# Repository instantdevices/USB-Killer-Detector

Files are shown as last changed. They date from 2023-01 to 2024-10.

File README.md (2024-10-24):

<p align="center">
    <strong>USB KILLER DETECTOR</strong>
</p>
<p>
UBS Kill is a pen-testing device that looks like a regular USB flash drive. When these USB flash drives are connected into a USB port of your personal computer, then the 5V found in the USB port is converted into about 220 Volts. Needless to say that the computer can be physically damaged in seconds, resulting in the spending of money and resources to replace broken parts.
</p>
<p>
<strong>Key Features:</strong>
</p>
<ul>
<li>
Detects these flash drives in seconds.
</li>
<li>
Fits in your hand and pocket.
</li>
<li>
Relatively low manufacturing costs.
</li>
<li>
Universally compatible with almost every micro-USB charger.
</li>
<li>
Use it prior to connect an unknown flash drive to your valuable hardware.
</li>
<li>
Confidently proceed as usual upon a negative result.
</li>
</ul>
<p>
<strong>Available Versions:</strong>
</p>
<ul>
<li>
Version #1: (Battery-Powered) This version uses a battery to source for energy. People can carry this device with them as it is portable.
</li>
<li>
Version #2: (No Battery-Powered) It is a commercial challenge to ship devices with an ion-based battery due to current global regulations. This version does NOT use any battery at all, instead, energy is sourced from a standard micro-USB charging cable.
</li>
</ul>

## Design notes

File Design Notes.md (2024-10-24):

<p align="center">
    <strong>DESIGN NOTES</strong>
</p>
<p><strong>Find notes below:</strong></p>
<ul>

<li>PCB is two-layer SMD.</strong></li>

<li>Design rules are Seeeds 2-layer standard rules.</li>

<li>Circuit has three sections, Micro USB charger, 5V boost converter and killer detector (including safety clamper).</li>

<li>
3-LEDs:
<ul>
<li>Power LED</li>
<li>Battery charger status LED</li>
<li>Killer detection LED</li>
</ul>
</li>

<li>Battery is 3.7V single cell Lithium Iron (1000mAh capacity). Charging current is 100mA (check schematic).</li>

<li>PCB size is mentioned in the given images. Basically ~3.6cmx6.2cm.</li>

<li>Mounting holes are 3mm.</li>

<li>The battery can be placed under the PCB. There is small rounded place to feed the battery wires from bottom side to top.</li>

<li>Some test points were added in case users need to check/debug circuit sections.</li>

<li>SJ1 jumper was added to reset the push button IC.</li>

<li>Additional external LED was added to the same Killer LED output. If users need to get out killer LED from the board to enclosure, skip board LED and R7 resistor and add R13 resistor. Then users can use EXT_LED header (2.54mm pitch) to drive external LED (LED will be standard 3mm, Vf=2.2V, If=20mA, these are approximates).</li>

<li>Added 4 fiducials for fab support.</li>

<li>S1 is the turn on/off button.</li>

<li>When a killer USB is detected, circuit will show the red LED output until removed. On low battery, red LED will turn on for the blink of an eye.</li>
</ul>

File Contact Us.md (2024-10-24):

<p align="center">
<strong>CONTACT INFORMATION</strong>
</p>
<p><em>
Instant Devices<br>
Attn: USB Killer Detector<br>
11425 SW 44th St<br>
Miami, FL 33165<br>
United States<br>
Email: instant.devices@yahoo.com
</em></p>

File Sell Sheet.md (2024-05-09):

<p align="center">
    <strong>USB KILLER DETECTOR</strong>
</p>
<p align="center">
    <strong></strong>
</p>
<p align="center">
    <strong>SELL SHEET</strong>
</p>
<p>
    UBS Kill is a pen-testing device that looks like a regular USB flash drive.
    When these USB flash drives are connected into a USB port of your personal computer, then the 5V found in the USB port is converted into
    about 220 Volts. Needless to say that the computer
    can be physically damaged in seconds, resulting in the spending of money and resources
    to replace broken parts.
</p>
<p>
    Key Features:
</p>
<p>
    - Detects these flash drives in seconds.
</p>
<p>
    - Fits in your hand and pocket.
</p>
<p>
    - Relatively low manufacturing costs.
</p>
<p>
    - Universally compatible with almost any micro-USB charger.
</p>
<p>
    - Use it prior to connect an unknown flash drive to your valuable hardware.
</p>
<p>
    - Confidently proceed as usual upon a negative result.
</p>

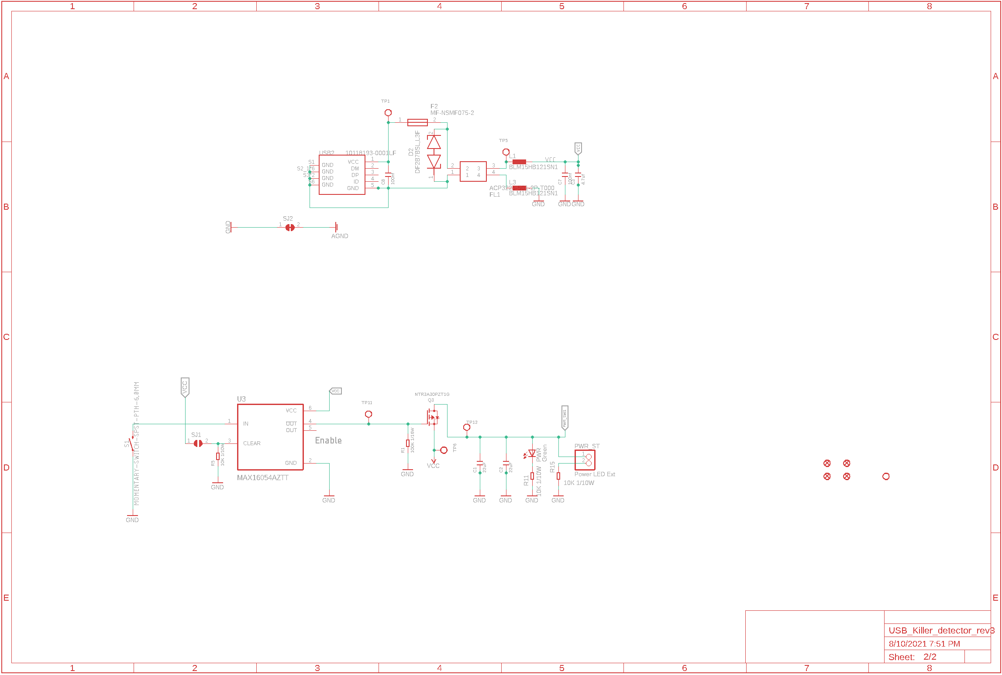
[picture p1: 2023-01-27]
Project/V2/Schematics/Schematics 2 of 2.png

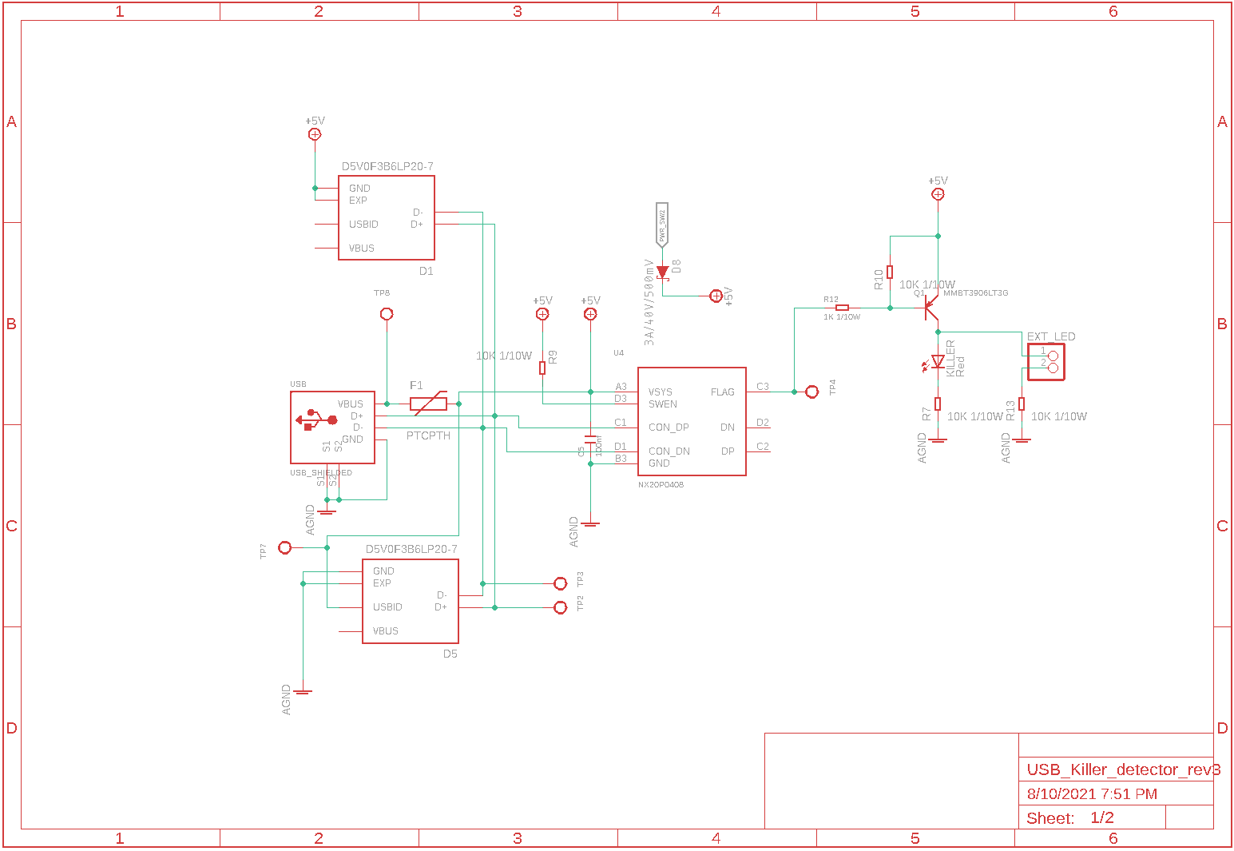
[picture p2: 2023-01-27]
Project/V2/Schematics/Schematics 1 of 2.png

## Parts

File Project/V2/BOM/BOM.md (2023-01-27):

<p align="center">
    <strong>USB KILLER DETECTOR V2</strong>
</p>
<p align="center">
    <strong></strong>
</p>
<p align="center">
    <strong>BOM</strong>
</p>
<table border="0" cellspacing="0" cellpadding="0" width="1333">
    <tbody>
        <tr>
            <td width="75" nowrap="" valign="bottom">
                <p>
                    <strong>Designator</strong>
                </p>
            </td>
            <td width="177" nowrap="" valign="bottom">
                <p>
                    <strong>Manufacturer Part Number</strong>
                </p>
            </td>
            <td width="1049" nowrap="" valign="bottom">
                <p>
                    <strong>DigiKey Link</strong>
                </p>
            </td>
            <td width="32" nowrap="" valign="bottom">
                <p>
                    <strong>Qty</strong>
                </p>
            </td>
        </tr>
        <tr>
            <td width="75" nowrap="" valign="bottom">
                <p>
                    C1
                </p>
            </td>
            <td width="177" nowrap="" valign="bottom">
                <p>
                    GRM319R61C226ME15D
                </p>
            </td>
            <td width="1049" nowrap="" valign="bottom">
                <p>
                    https://www.digikey.com/en/products/detail/murata-electronics/GRM319R61C226ME15D/4905568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
                </p>
            </td>
            <td width="32" nowrap="" valign="bottom">
                <p align="center">
                    1
                </p>
            </td>
        </tr>
        <tr>
            <td width="75" nowrap="" valign="bottom">
                <p>
                    C2
                </p>
            </td>
            <td width="177" nowrap="" valign="bottom">
                <p>
                    GRM319R61C226ME15D
                </p>
            </td>
            <td width="1049" nowrap="" valign="bottom">
                <p>
                    https://www.digikey.com/en/products/detail/murata-electronics/GRM319R61C226ME15D/4905568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
                </p>
            </td>
            <td width="32" nowrap="" valign="bottom">
                <p align="center">
                    1
                </p>
            </td>
        </tr>
        <tr>
            <td width="75" nowrap="" valign="bottom">
                <p>
                    C3
                </p>
            </td>
            <td width="177" nowrap="" valign="bottom">
                <p>
                    CC0805KKX5R8BB475
                </p>
            </td>
            <td width="1049" nowrap="" valign="bottom">
                <p>
                    https://www.digikey.com/en/products/detail/yageo/CC0805KKX5R8BB475/5195277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
                </p>
            </td>
            <td width="32" nowrap="" valign="bottom">
                <p align="center">
                    1
                </p>
            </td>
        </tr>
        <tr>
            <td width="75" nowrap="" valign="bottom">
                <p>
                    C5
                </p>
            </td>
            <td width="177" nowrap="" valign="bottom">
                <p>
                    CC0805KRX7R9BB104
                </p>
            </td>
            <td width="1049" nowrap="" valign="bottom">
                <p>
                    https://www.digikey.com/en/products/detail/yageo/CC0805KRX7R9BB104/302874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
                </p>
            </td>
            <td width="32" nowrap="" valign="bottom">
                <p align="center">
                    1
                </p>
            </td>
        </tr>
        <tr>
            <td width="75" nowrap="" valign="bottom">
                <p>
                    C7
                </p>
            </td>
            <td width="177" nowrap="" valign="bottom">
                <p>
                    CC0805KRX7R9BB104
                </p>
            </td>
            <td width="1049" nowrap="" valign="bottom">
                <p>
                    https://www.digikey.com/en/products/detail/yageo/CC0805KRX7R9BB104/302874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
                </p>
            </td>
            <td width="32" nowrap="" valign="bottom">
                <p align="center">
                    1
                </p>
            </td>
        </tr>
        <tr>
            <td width="75" nowrap="" valign="bottom">
                <p>
                    C8
                </p>
            </td>
            <td width="177" nowrap="" valign="bottom">
                <p>
                    CC0805KRX7R9BB104
                </p>
            </td>
            <td width="1049" nowrap="" valign="bottom">
                <p>
                    https://www.digikey.com/en/products/detail/yageo/CC0805KRX7R9BB104/302874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
                </p>
            </td>
            <td width="32" nowrap="" valign="bottom">
                <p align="center">
                    1
                </p>
            </td>
        </tr>
        <tr>
            <td width="75" nowrap="" valign="bottom">
                <p>
                    D1
                </p>
            </td>
            <td width="177" nowrap="" valign="bottom">
                <p>
                    D5V0F3B6LP20-7
                </p>
            </td>
            <td width="1049" nowrap="" valign="bottom">
                <p>
                    https://www.digikey.com/en/products/detail/diodes-incorporated/D5V0F3B6LP20-7/5255844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
                </p>
            </td>
            <td width="32" nowrap="" valign="bottom">
                <p align="center">
                    1
                </p>
            </td>
        </tr>
        <tr>
            <td width="75" nowrap="" valign="bottom">
                <p>
                    D2
                </p>
            </td>
            <td width="177" nowrap="" valign="bottom">
                <p>
                    DF2B7BSL,L3F
                </p>
            </td>
            <td width="1049" nowrap="" valign="bottom">
                <p>
                    https://www.digikey.com/en/products/detail/toshiba-semiconductor-and-storage/DF2B7BSL-L3F/10663155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
                </p>
            </td>
            <td width="32" nowrap="" valign="bottom">
                <p align="center">
                    1
                </p>
            </td>
        </tr>
        <tr>
            <td width="75" nowrap="" valign="bottom">
                <p>
                    D5
                </p>
            </td>
            <td width="177" nowrap="" valign="bottom">
                <p>
                    D5V0F3B6LP20-7
                </p>
            </td>
            <td width="1049" nowrap="" valign="bottom">
                <p>
                    https://www.digikey.com/en/products/detail/diodes-incorporated/D5V0F3B6LP20-7/5255844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
                </p>
            </td>
            <td width="32" nowrap="" valign="bottom">
                <p align="center">
                    1
                </p>
            </td>
        </tr>
        <tr>
            <td width="75" nowrap="" valign="bottom">
                <p>
                    D8
                </p>
            </td>
            <td width="177" nowrap="" valign="bottom">
                <p>
                    B340A-13-F
                </p>
            </td>
            <td width="1049" nowrap="" valign="bottom">
                <p>
                    https://www.digikey.com/en/products/detail/diodes-incorporated/B340A-13-F/725015
                </p>
            </td>
            <td width="32" nowrap="" valign="bottom">
                <p align="center">
                    1
                </p>
            </td>
        </tr>
        <tr>
            <td width="75" nowrap="" valign="bottom">
                <p>
                    EXT_LED
                </p>
            </td>
            <td width="177" nowrap="" valign="bottom">
                <p>
                    L314ED
                </p>
            </td>
            <td width="1049" nowrap="" valign="bottom">
                <p>
                    https://www.digikey.com/en/products/detail/american-opto-plus-led/L314ED/13677700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
                </p>
            </td>
            <td width="32" nowrap="" valign="bottom">
                <p align="center">
                    1
                </p>
            </td>
        </tr>
        <tr>
            <td width="75" nowrap="" valign="bottom">
                <p>
                    F1
                </p>
            </td>
            <td width="177" nowrap="" valign="bottom">
                <p>
                    PTGL07BB220N0B52A0
                </p>
            </td>
            <td width="1049" nowrap="" valign="bottom">
                <p>
                    https://www.digikey.com/en/products/detail/murata-electronics/PTGL07BB220N0B52A0/1644689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
                </p>
            </td>
            <td width="32" nowrap="" valign="bottom">
                <p align="center">
                    1
                </p>
            </td>
        </tr>
        <tr>
            <td width="75" nowrap="" valign="bottom">
                <p>
                    F2
                </p>
            </td>
            <td width="177" nowrap="" valign="bottom">
                <p>
                    MF-NSMF075-2
                </p>
            </td>
            <td width="1049" nowrap="" valign="bottom">
                <p>
                    https://www.digikey.com/en/products/detail/bourns-inc/MF-NSMF075-2/662809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
                </p>
            </td>
            <td width="32" nowrap="" valign="bottom">
                <p align="center">
                    1
                </p>
            </td>
        </tr>
        <tr>
            <td width="75" nowrap="" valign="bottom">
                <p>
                    FL1
                </p>
            </td>
            <td width="177" nowrap="" valign="bottom">
                <p>
                    ACP3225-501-2P-T000
                </p>
            </td>
            <td width="1049" nowrap="" valign="bottom">
                <p>
                    https://www.digikey.com/en/products/detail/tdk-corporation/ACP3225-501-2P-T000/4966208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
                </p>
            </td>
            <td width="32" nowrap="" valign="bottom">
                <p align="center">
                    1
                </p>
            </td>
        </tr>
        <tr>
            <td width="75" nowrap="" valign="bottom">
                <p>
                    KILLER
                </p>
            </td>
            <td width="177" nowrap="" valign="bottom">
                <p>
                    HSMC-C190
                </p>
            </td>
            <td width="1049" nowrap="" valign="bottom">
                <p>
                    https://www.digikey.com/en/products/detail/broadcom-limited/HSMC-C190/637682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
                </p>
            </td>
            <td width="32" nowrap="" valign="bottom">
                <p align="center">
                    1
                </p>
            </td>
        </tr>
        <tr>
            <td width="75" nowrap="" valign="bottom">
                <p>
                    L1
                </p>
            </td>
            <td width="177" nowrap="" valign="bottom">
                <p>
                    BLM15HB121SN1D
                </p>
            </td>
            <td width="1049" nowrap="" valign="bottom">
                <p>
                    https://www.digikey.com/en/products/detail/murata-electronics/BLM15HB121SN1D/1016159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
                </p>
            </td>
            <td width="32" nowrap="" valign="bottom">
                <p align="center">
                    1
                </p>
            </td>
        </tr>
        <tr>
            <td width="75" nowrap="" valign="bottom">
                <p>
                    L3
                </p>
            </td>
            <td width="177" nowrap="" valign="bottom">
                <p>
                    BLM15HB121SN1D
                </p>
            </td>
            <td width="1049" nowrap="" valign="bottom">
                <p>
                    https://www.digikey.com/en/products/detail/murata-electronics/BLM15HB121SN1D/1016159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
                </p>
            </td>
            <td width="32" nowrap="" valign="bottom">
                <p align="center">
                    1
                </p>
            </td>
        </tr>
        <tr>
            <td width="75" nowrap="" valign="bottom">
                <p>
                    PWR
                </p>
            </td>
            <td width="177" nowrap="" valign="bottom">
                <p>
                    HSMG-C190
                </p>
            </td>
            <td width="1049" nowrap="" valign="bottom">
                <p>
                    https://www.digikey.com/en/products/detail/broadcom-limited/HSMG-C190/637686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
                </p>
            </td>
            <td width="32" nowrap="" valign="bottom">
                <p align="center">
                    1
                </p>
            </td>
        </tr>
        <tr>
            <td width="75" nowrap="" valign="bottom">
                <p>
                    PWR_ST
                </p>
            </td>
            <td width="177" nowrap="" valign="bottom">
                <p>
                    151031VS06000
                </p>
            </td>
            <td width="1049" nowrap="" valign="bottom">
                <p>
                    https://www.digikey.com/en/products/detail/w%C3%BCrth-elektronik/151031VS06000/4489988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
                </p>
            </td>
            <td width="32" nowrap="" valign="bottom">
                <p align="center">
                    1
                </p>
            </td>
        </tr>
        <tr>
            <td width="75" nowrap="" valign="bottom">
                <p>
                    Q1
                </p>
            </td>
            <td width="177" nowrap="" valign="bottom">
                <p>
                    MMBT3906LT3G
                </p>
            </td>
            <td width="1049" nowrap="" valign="bottom">
                <p>
                    https://www.digikey.com/en/products/detail/on-semiconductor/MMBT3906LT3G/1481939
                </p>
            </td>
            <td width="32" nowrap="" valign="bottom">
                <p align="center">
                    1
                </p>
            </td>
        </tr>
        <tr>
            <td width="75" nowrap="" valign="bottom">
                <p>
                    Q3
                </p>
            </td>
            <td width="177" nowrap="" valign="bottom">
                <p>
                    NTR3A30PZT1G
                </p>
            </td>
            <td width="1049" nowrap="" valign="bottom">
                <p>
                    https://www.digikey.com/en/products/detail/on-semiconductor/NTR3A30PZT1G/4848848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
                </p>
            </td>
            <td width="32" nowrap="" valign="bottom">
                <p align="center">
                    1
                </p>
            </td>
        </tr>
        <tr>
            <td width="75" nowrap="" valign="bottom">
                <p>
                    R10
                </p>
            </td>
            <td width="177" nowrap="" valign="bottom">
                <p>
                    RC0603JR-0710KL
                </p>
            </td>
            <td width="1049" nowrap="" valign="bottom">
                <p>
                    https://www.digikey.com/en/products/detail/yageo/RC0603JR-0710KL/726700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
                </p>
            </td>
            <td width="32" nowrap="" valign="bottom">
                <p align="center">
                    1
                </p>
            </td>
        </tr>
        <tr>
            <td width="75" nowrap="" valign="bottom">
                <p>
                    R11
                </p>
            </td>
            <td width="177" nowrap="" valign="bottom">
                <p>
                    RC0603JR-0710KL
                </p>
            </td>
            <td width="1049" nowrap="" valign="bottom">
                <p>
                    https://www.digikey.com/en/products/detail/yageo/RC0603JR-0710KL/726700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
                </p>
            </td>
            <td width="32" nowrap="" valign="bottom">
                <p align="center">
                    1
                </p>
            </td>
        </tr>
        <tr>
            <td width="75" nowrap="" valign="bottom">
                <p>
                    R12
                </p>
            </td>
            <td width="177" nowrap="" valign="bottom">
                <p>
                    RC0603JR-071KL
                </p>
            </td>
            <td width="1049" nowrap="" valign="bottom">
                <p>
                    https://www.digikey.com/en/products/detail/yageo/RC0603JR-071KL/726677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
                </p>
            </td>
            <td width="32" nowrap="" valign="bottom">
                <p align="center">
                    1
                </p>
            </td>
        </tr>
        <tr>
            <td width="75" nowrap="" valign="bottom">
                <p>
                    R13
                </p>
            </td>
            <td width="177" nowrap="" valign="bottom">
                <p>
                    RC0603JR-0710KL
                </p>
            </td>
            <td width="1049" nowrap="" valign="bottom">
                <p>
                    https://www.digikey.com/en/products/detail/yageo/RC0603JR-0710KL/726700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
                </p>
            </td>
            <td width="32" nowrap="" valign="bottom">
                <p align="center">
                    1
                </p>
            </td>
        </tr>
        <tr>
            <td width="75" nowrap="" valign="bottom">
                <p>
                    R15
                </p>
            </td>
            <td width="177" nowrap="" valign="bottom">
                <p>
                    RC0603JR-0710KL
                </p>
            </td>
            <td width="1049" nowrap="" valign="bottom">
                <p>
                    https://www.digikey.com/en/products/detail/yageo/RC0603JR-0710KL/726700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
                </p>
            </td>
            <td width="32" nowrap="" valign="bottom">
                <p align="center">
                    1
                </p>
            </td>
        </tr>
        <tr>
            <td width="75" nowrap="" valign="bottom">
                <p>
                    R5
                </p>
            </td>
            <td width="177" nowrap="" valign="bottom">
                <p>
                    RC0603JR-0710KL
                </p>
            </td>
            <td width="1049" nowrap="" valign="bottom">
                <p>
                    https://www.digikey.com/en/products/detail/yageo/RC0603JR-0710KL/726700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
                </p>
            </td>
            <td width="32" nowrap="" valign="bottom">
                <p align="center">
                    1
                </p>
            </td>
        </tr>
        <tr>
            <td width="75" nowrap="" valign="bottom">
                <p>
                    R7
                </p>
            </td>
            <td width="177" nowrap="" valign="bottom">
                <p>
                    RC0603JR-0710KL
                </p>
            </td>
            <td width="1049" nowrap="" valign="bottom">
                <p>
                    https://www.digikey.com/en/products/detail/yageo/RC0603JR-0710KL/726700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
                </p>
            </td>
            <td width="32" nowrap="" valign="bottom">
                <p align="center">
                    1
                </p>
            </td>
        </tr>
        <tr>
            <td width="75" nowrap="" valign="bottom">
                <p>
                    R9
                </p>
            </td>
            <td width="177" nowrap="" valign="bottom">
                <p>
                    RC0603JR-0710KL
                </p>
            </td>
            <td width="1049" nowrap="" valign="bottom">
                <p>
                    https://www.digikey.com/en/products/detail/yageo/RC0603JR-0710KL/726700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
                </p>
            </td>
            <td width="32" nowrap="" valign="bottom">
                <p align="center">
                    1
                </p>
            </td>
        </tr>
        <tr>
            <td width="75" nowrap="" valign="bottom">
                <p>
                    S1
                </p>
            </td>
            <td width="177" nowrap="" valign="bottom">
                <p>
                    B3F-1070
                </p>
            </td>
            <td width="1049" nowrap="" valign="bottom">
                <p>
                    https://www.digikey.com/en/products/detail/omron-electronics-inc-emc-div/B3F-1070/38362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
                </p>
            </td>
            <td width="32" nowrap="" valign="bottom">
                <p align="center">
                    1
                </p>
            </td>
        </tr>
        <tr>
            <td width="75" nowrap="" valign="bottom">
                <p>
                    U3
                </p>
            </td>
            <td width="177" nowrap="" valign="bottom">
                <p>
                    MAX16054AZT+T
                </p>
            </td>
            <td width="1049" nowrap="" valign="bottom">
                <p>
                    https://www.digikey.com/en/products/detail/maxim-integrated/MAX16054AZT-T/1938114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
                </p>
            </td>
            <td width="32" nowrap="" valign="bottom">
                <p align="center">
                    1
                </p>
            </td>
        </tr>
        <tr>
            <td width="75" nowrap="" valign="bottom">
                <p>
                    U4
                </p>
            </td>
            <td width="177" nowrap="" valign="bottom">
                <p>
                    NX20P0408UKZ
                </p>
            </td>
            <td width="1049" nowrap="" valign="bottom">
                <p>
                    https://www.digikey.com/en/products/detail/nxp-usa-inc/NX20P0408UKZ/9955462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
                </p>
            </td>
            <td width="32" nowrap="" valign="bottom">
                <p align="center">
                    1
                </p>
            </td>
        </tr>
        <tr>
            <td width="75" nowrap="" valign="bottom">
                <p>
                    USB
                </p>
            </td>
            <td width="177" nowrap="" valign="bottom">
                <p>
                    87520-0010BLF
                </p>
            </td>
            <td width="1049" nowrap="" valign="bottom">
                <p>
                    https://www.digikey.com/en/products/detail/amphenol-icc-fci/87520-0010BLF/1001359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
                </p>
            </td>
            <td width="32" nowrap="" valign="bottom">
                <p align="center">
                    1
                </p>
            </td>
        </tr>
        <tr>
            <td width="75" nowrap="" valign="bottom">
                <p>
                    USB2
                </p>
            </td>
            <td width="177" nowrap="" valign="bottom">
                <p>
                    10118193-0001LF
                </p>
            </td>
            <td width="1049" nowrap="" valign="bottom">
                <p>
                    https://www.digikey.com/en/products/detail/amphenol-icc-fci/10118193-0001LF/2785388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
                </p>
            </td>
            <td width="32" nowrap="" valign="bottom">
                <p align="center">
                    1
                </p>
            </td>
        </tr>
    </tbody>
</table>

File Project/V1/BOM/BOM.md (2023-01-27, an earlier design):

<p align="center">
    <strong>USB KILLER DETECTOR V1</strong>
</p>
<p align="center">
    <strong></strong>
</p>
<p align="center">
    <strong>BOM</strong>
</p>
<table border="0" cellspacing="0" cellpadding="0" width="872">
    <tbody>
        <tr>
            <td width="59" nowrap="" valign="bottom">
                <p>
                    <strong>Part</strong>
                </p>
            </td>
            <td width="259" nowrap="" valign="bottom">
                <p>
                    <strong>Value</strong>
                </p>
            </td>
            <td width="175" nowrap="" valign="bottom">
                <p>
                    <strong>DIGIKEY</strong>
                </p>
            </td>
            <td width="155" nowrap="" valign="bottom">
                <p>
                    <strong>MPN</strong>
                </p>
            </td>
            <td width="196" nowrap="" valign="bottom">
                <p>
                    <strong>Package</strong>
                </p>
            </td>
            <td width="29" nowrap="" valign="bottom">
                <p>
                    <strong>Qty</strong>
                </p>
            </td>
        </tr>
        <tr>
            <td width="59" nowrap="" valign="bottom">
                <p>
                    Battery
                </p>
            </td>
            <td width="259" nowrap="" valign="bottom">
                <p>
                    3.7V 1000mAh
                </p>
            </td>
            <td width="175" nowrap="" valign="bottom">
                <p>
                    1568-1492-ND
                </p>
            </td>
            <td width="155" nowrap="" valign="bottom">
                <p>
                    PRT-13813
                </p>
            </td>
            <td width="196" nowrap="" valign="bottom">
            </td>
            <td width="29" nowrap="" valign="bottom">
                <p align="right">
                    1
                </p>
            </td>
        </tr>
        <tr>
            <td width="59" nowrap="" valign="bottom">
                <p>
                    BT1
                </p>
            </td>
            <td width="259" nowrap="" valign="bottom">
                <p>
                    Battery
                </p>
            </td>
            <td width="175" nowrap="" valign="bottom">
                <p>
                    455-1749-1-ND
                </p>
            </td>
            <td width="155" nowrap="" valign="bottom">
                <p>
                    S2B-PH-SM4-TB(LF)(SN)
                </p>
            </td>
            <td width="196" nowrap="" valign="bottom">
                <p>
                    SON65P200X200X63-7N
                </p>
            </td>
            <td width="29" nowrap="" valign="bottom">
                <p align="right">
                    1
                </p>
            </td>
        </tr>
        <tr>
            <td width="59" nowrap="" valign="bottom">
                <p>
                    C_ST
                </p>
            </td>
            <td width="259" nowrap="" valign="bottom">
                <p>
                    External Led Yellow
                </p>
            </td>
            <td width="175" nowrap="" valign="bottom">
                <p>
                    2460-L314YD-ND
                </p>
            </td>
            <td width="155" nowrap="" valign="bottom">
                <p>
                    L314YD
                </p>
            </td>
            <td width="196" nowrap="" valign="bottom">
            </td>
            <td width="29" nowrap="" valign="bottom">
                <p align="right">
                    1
                </p>
            </td>
        </tr>
        <tr>
            <td width="59" nowrap="" valign="bottom">
                <p>
                    C1
                </p>
            </td>
            <td width="259" nowrap="" valign="bottom">
                <p>
                    22uF
                </p>
            </td>
            <td width="175" nowrap="" valign="bottom">
                <p>
                    490-12763-1-ND
                </p>
            </td>
            <td width="155" nowrap="" valign="bottom">
                <p>
                    GRM319R61C226ME15D
                </p>
            </td>
            <td width="196" nowrap="" valign="bottom">
                <p>
                    C1206
                </p>
            </td>
            <td width="29" nowrap="" valign="bottom">
                <p align="right">
                    1
                </p>
            </td>
        </tr>
        <tr>
            <td width="59" nowrap="" valign="bottom">
                <p>
                    C2
                </p>
            </td>
            <td width="259" nowrap="" valign="bottom">
                <p>
                    22uF
                </p>
            </td>
            <td width="175" nowrap="" valign="bottom">
                <p>
                    490-12763-1-ND
                </p>
            </td>
            <td width="155" nowrap="" valign="bottom">
                <p>
                    GRM319R61C226ME15D
                </p>
            </td>
            <td width="196" nowrap="" valign="bottom">
                <p>
                    C1206
                </p>
            </td>
            <td width="29" nowrap="" valign="bottom">
                <p align="right">
                    1
                </p>
            </td>
        </tr>
        <tr>
            <td width="59" nowrap="" valign="bottom">
                <p>
                    C3
                </p>
            </td>
            <td width="259" nowrap="" valign="bottom">
                <p>
                    4.7uf
                </p>
            </td>
            <td width="175" nowrap="" valign="bottom">
                <p>
                    311-1871-1-ND
                </p>
            </td>
            <td width="155" nowrap="" valign="bottom">
                <p>
                    CC0805KKX5R8BB475
                </p>
            </td>
            <td width="196" nowrap="" valign="bottom">
                <p>
                    C0805
                </p>
            </td>
            <td width="29" nowrap="" valign="bottom">
                <p align="right">
                    1
                </p>
            </td>
        </tr>
        <tr>
            <td width="59" nowrap="" valign="bottom">
                <p>
                    C4
                </p>
            </td>
            <td width="259" nowrap="" valign="bottom">
                <p>
                    4.7uf
                </p>
            </td>
            <td width="175" nowrap="" valign="bottom">
                <p>
                    311-1871-1-ND
                </p>
            </td>
            <td width="155" nowrap="" valign="bottom">
                <p>
                    CC0805KKX5R8BB475
                </p>
            </td>
            <td width="196" nowrap="" valign="bottom">
                <p>
                    R0603
                </p>
            </td>
            <td width="29" nowrap="" valign="bottom">
                <p align="right">
                    1
                </p>
            </td>
        </tr>
        <tr>
            <td width="59" nowrap="" valign="bottom">
                <p>
                    C5
                </p>
            </td>
            <td width="259" nowrap="" valign="bottom">
                <p>
                    100nf
                </p>
            </td>
            <td width="175" nowrap="" valign="bottom">
                <p>
                    311-1140-1-ND
                </p>
            </td>
            <td width="155" nowrap="" valign="bottom">
                <p>
                    CC0805KRX7R9BB104
                </p>
            </td>
            <td width="196" nowrap="" valign="bottom">
                <p>
                    C0805
                </p>
            </td>
            <td width="29" nowrap="" valign="bottom">
                <p align="right">
                    1
                </p>
            </td>
        </tr>
        <tr>
            <td width="59" nowrap="" valign="bottom">
                <p>
                    C6
                </p>
            </td>
            <td width="259" nowrap="" valign="bottom">
                <p>
                    22uF
                </p>
            </td>
            <td width="175" nowrap="" valign="bottom">
                <p>
                    490-12763-1-ND
                </p>
            </td>
            <td width="155" nowrap="" valign="bottom">
                <p>
                    GRM319R61C226ME15D
                </p>
            </td>
            <td width="196" nowrap="" valign="bottom">
                <p>
                    SMA-DIODE
                </p>
            </td>
            <td width="29" nowrap="" valign="bottom">
                <p align="right">
                    1
                </p>
            </td>
        </tr>
        <tr>
            <td width="59" nowrap="" valign="bottom">
                <p>
                    D1
                </p>
            </td>
            <td width="259" nowrap="" valign="bottom">
                <p>
                    D5V0F3B6LP20-7
                </p>
            </td>
            <td width="175" nowrap="" valign="bottom">
                <p>
                    D5V0F3B6LP20-7DICT-ND
                </p>
            </td>
            <td width="155" nowrap="" valign="bottom">
                <p>
                    D5V0F3B6LP20-7
                </p>
            </td>
            <td width="196" nowrap="" valign="bottom">
                <p>
                    SON65P200X200X63-7N
                </p>
            </td>
            <td width="29" nowrap="" valign="bottom">
                <p align="right">
                    1
                </p>
            </td>
        </tr>
        <tr>
            <td width="59" nowrap="" valign="bottom">
                <p>
                    D5
                </p>
            </td>
            <td width="259" nowrap="" valign="bottom">
                <p>
                    D5V0F3B6LP20-7
                </p>
            </td>
            <td width="175" nowrap="" valign="bottom">
                <p>
                    D5V0F3B6LP20-7DICT-ND
                </p>
            </td>
            <td width="155" nowrap="" valign="bottom">
                <p>
                    D5V0F3B6LP20-7
                </p>
            </td>
            <td width="196" nowrap="" valign="bottom">
                <p>
                    FIDUCIAL-1X2
                </p>
            </td>
            <td width="29" nowrap="" valign="bottom">
                <p align="right">
                    1
                </p>
            </td>
        </tr>
        <tr>
            <td width="59" nowrap="" valign="bottom">
                <p>
                    D8
                </p>
            </td>
            <td width="259" nowrap="" valign="bottom">
                <p>
                    3A/40V/500mV
                </p>
            </td>
            <td width="175" nowrap="" valign="bottom">
                <p>
                    B340A-FDICT-ND
                </p>
            </td>
            <td width="155" nowrap="" valign="bottom">
                <p>
                    B340A-13-F
                </p>
            </td>
            <td width="196" nowrap="" valign="bottom">
                <p>
                    C0805
                </p>
            </td>
            <td width="29" nowrap="" valign="bottom">
                <p align="right">
                    1
                </p>
            </td>
        </tr>
        <tr>
            <td width="59" nowrap="" valign="bottom">
                <p>
                    EXT_LED
                </p>
            </td>
            <td width="259" nowrap="" valign="bottom">
                <p>
                    External Led Red
                </p>
            </td>
            <td width="175" nowrap="" valign="bottom">
                <p>
                    2460-L314ED-ND
                </p>
            </td>
            <td width="155" nowrap="" valign="bottom">
                <p>
                    L314ED
                </p>
            </td>
            <td width="196" nowrap="" valign="bottom">
            </td>
            <td width="29" nowrap="" valign="bottom">
                <p align="right">
                    1
                </p>
            </td>
        </tr>
        <tr>
            <td width="59" nowrap="" valign="bottom">
                <p>
                    F1
                </p>
            </td>
            <td width="259" nowrap="" valign="bottom">
                <p>
                    PTCPTH
                </p>
            </td>
            <td width="175" nowrap="" valign="bottom">
                <p>
                    490-4808-1-ND
                </p>
            </td>
            <td width="155" nowrap="" valign="bottom">
                <p>
                    PTGL07BB220N0B52A0
                </p>
            </td>
            <td width="196" nowrap="" valign="bottom">
                <p>
                    TACTILE_SWITCH_PTH_6.0MM
                </p>
            </td>
            <td width="29" nowrap="" valign="bottom">
                <p align="right">
                    1
                </p>
            </td>
        </tr>
        <tr>
            <td width="59" nowrap="" valign="bottom">
                <p>
                    KILLER
                </p>
            </td>
            <td width="259" nowrap="" valign="bottom">
                <p>
                    Red
                </p>
            </td>
            <td width="175" nowrap="" valign="bottom">
                <p>
                    516-1421-1-ND
                </p>
            </td>
            <td width="155" nowrap="" valign="bottom">
                <p>
                    HSMC-C190
                </p>
            </td>
            <td width="196" nowrap="" valign="bottom">
                <p>
                    BGA12N40P3X4_119X159X62N
                </p>
            </td>
            <td width="29" nowrap="" valign="bottom">
                <p align="right">
                    1
                </p>
            </td>
        </tr>
        <tr>
            <td width="59" nowrap="" valign="bottom">
                <p>
                    L2
                </p>
            </td>
            <td width="259" nowrap="" valign="bottom">
                <p>
                    2.2UH-1.2A
                </p>
            </td>
            <td width="175" nowrap="" valign="bottom">
                <p>
                    490-12072-1-ND
                </p>
            </td>
            <td width="155" nowrap="" valign="bottom">
                <p>
                    LQM2MPN2R2MG0
                </p>
            </td>
            <td width="196" nowrap="" valign="bottom">
                <p>
                    C1206
                </p>
            </td>
            <td width="29" nowrap="" valign="bottom">
                <p align="right">
                    1
                </p>
            </td>
        </tr>
        <tr>
            <td width="59" nowrap="" valign="bottom">
                <p>
                    PWR
                </p>
            </td>
            <td width="259" nowrap="" valign="bottom">
                <p>
                    Green
                </p>
            </td>
            <td width="175" nowrap="" valign="bottom">
                <p>
                    516-1425-1-ND
                </p>
            </td>
            <td width="155" nowrap="" valign="bottom">
                <p>
                    HSMG-C190
                </p>
            </td>
            <td width="196" nowrap="" valign="bottom">
                <p>
                    FIDUCIAL-1X2
                </p>
            </td>
            <td width="29" nowrap="" valign="bottom">
                <p align="right">
                    1
                </p>
            </td>
        </tr>
        <tr>
            <td width="59" nowrap="" valign="bottom">
                <p>
                    PWR_ST
                </p>
            </td>
            <td width="259" nowrap="" valign="bottom">
                <p>
                    External Led Green
                </p>
            </td>
            <td width="175" nowrap="" valign="bottom">
                <p>
                    2460-L314GT-ND
                </p>
            </td>
            <td width="155" nowrap="" valign="bottom">
                <p>
                    L314GT
                </p>
            </td>
            <td width="196" nowrap="" valign="bottom">
            </td>
            <td width="29" nowrap="" valign="bottom">
                <p align="right">
                    1
                </p>
            </td>
        </tr>
        <tr>
            <td width="59" nowrap="" valign="bottom">
                <p>
                    Q1
                </p>
            </td>
            <td width="259" nowrap="" valign="bottom">
                <p>
                    MMBT3906LT3G
                </p>
            </td>
            <td width="175" nowrap="" valign="bottom">
                <p>
                    MMBT3906LT3GOSCT-ND
                </p>
            </td>
            <td width="155" nowrap="" valign="bottom">
                <p>
                    MMBT3906LT3G
                </p>
            </td>
            <td width="196" nowrap="" valign="bottom">
                <p>
                    0603-LED-ALT1
                </p>
            </td>
            <td width="29" nowrap="" valign="bottom">
                <p align="right">
                    1
                </p>
            </td>
        </tr>
        <tr>
            <td width="59" nowrap="" valign="bottom">
                <p>
                    R1
                </p>
            </td>
            <td width="259" nowrap="" valign="bottom">
                <p>
                    10K 1/10W
                </p>
            </td>
            <td width="175" nowrap="" valign="bottom">
                <p>
                    311-10KGRCT-ND
                </p>
            </td>
            <td width="155" nowrap="" valign="bottom">
                <p>
                    RC0603JR-0710KL
                </p>
            </td>
            <td width="196" nowrap="" valign="bottom">
                <p>
                    R0603
                </p>
            </td>
            <td width="29" nowrap="" valign="bottom">
                <p align="right">
                    1
                </p>
            </td>
        </tr>
        <tr>
            <td width="59" nowrap="" valign="bottom">
                <p>
                    R10
                </p>
            </td>
            <td width="259" nowrap="" valign="bottom">
                <p>
                    10K 1/10W
                </p>
            </td>
            <td width="175" nowrap="" valign="bottom">
                <p>
                    311-10KGRCT-ND
                </p>
            </td>
            <td width="155" nowrap="" valign="bottom">
                <p>
                    RC0603JR-0710KL
                </p>
            </td>
            <td width="196" nowrap="" valign="bottom">
                <p>
                    R0603
                </p>
            </td>
            <td width="29" nowrap="" valign="bottom">
                <p align="right">
                    1
                </p>
            </td>
        </tr>
        <tr>
            <td width="59" nowrap="" valign="bottom">
                <p>
                    R11
                </p>
            </td>
            <td width="259" nowrap="" valign="bottom">
                <p>
                    10K 1/10W
                </p>
            </td>
            <td width="175" nowrap="" valign="bottom">
                <p>
                    311-10KGRCT-ND
                </p>
            </td>
            <td width="155" nowrap="" valign="bottom">
                <p>
                    RC0603JR-0710KL
                </p>
            </td>
            <td width="196" nowrap="" valign="bottom">
                <p>
                    R0603
                </p>
            </td>
            <td width="29" nowrap="" valign="bottom">
                <p align="right">
                    1
                </p>
            </td>
        </tr>
        <tr>
            <td width="59" nowrap="" valign="bottom">
                <p>
                    R12
                </p>
            </td>
            <td width="259" nowrap="" valign="bottom">
                <p>
                    1K 1/10W
                </p>
            </td>
            <td width="175" nowrap="" valign="bottom">
                <p>
                    311-1.0KGRCT-ND
                </p>
            </td>
            <td width="155" nowrap="" valign="bottom">
                <p>
                    RC0603JR-071KL
                </p>
            </td>
            <td width="196" nowrap="" valign="bottom">
                <p>
                    L0805
                </p>
            </td>
            <td width="29" nowrap="" valign="bottom">
                <p align="right">
                    1
                </p>
            </td>
        </tr>
        <tr>
            <td width="59" nowrap="" valign="bottom">
                <p>
                    R13
                </p>
            </td>
            <td width="259" nowrap="" valign="bottom">
                <p>
                    10K 1/10W
                </p>
            </td>
            <td width="175" nowrap="" valign="bottom">
                <p>
                    311-10KGRCT-ND
                </p>
            </td>
            <td width="155" nowrap="" valign="bottom">
                <p>
                    RC0603JR-0710KL
                </p>
            </td>
            <td width="196" nowrap="" valign="bottom">
                <p>
                    R0603
                </p>
            </td>
            <td width="29" nowrap="" valign="bottom">
                <p align="right">
                    1
                </p>
            </td>
        </tr>
        <tr>
            <td width="59" nowrap="" valign="bottom">
                <p>
                    R14
                </p>
            </td>
            <td width="259" nowrap="" valign="bottom">
                <p>
                    10K 1/10W
                </p>
            </td>
            <td width="175" nowrap="" valign="bottom">
                <p>
                    311-10KGRCT-ND
                </p>
            </td>
            <td width="155" nowrap="" valign="bottom">
                <p>
                    RC0603JR-0710KL
                </p>
            </td>
            <td width="196" nowrap="" valign="bottom">
                <p>
                    R0603
                </p>
            </td>
            <td width="29" nowrap="" valign="bottom">
                <p align="right">
                    1
                </p>
            </td>
        </tr>
        <tr>
            <td width="59" nowrap="" valign="bottom">
                <p>
                    R15
                </p>
            </td>
            <td width="259" nowrap="" valign="bottom">
                <p>
                    10K 1/10W
                </p>
            </td>
            <td width="175" nowrap="" valign="bottom">
                <p>
                    311-10KGRCT-ND
                </p>
            </td>
            <td width="155" nowrap="" valign="bottom">
                <p>
                    RC0603JR-0710KL
                </p>
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

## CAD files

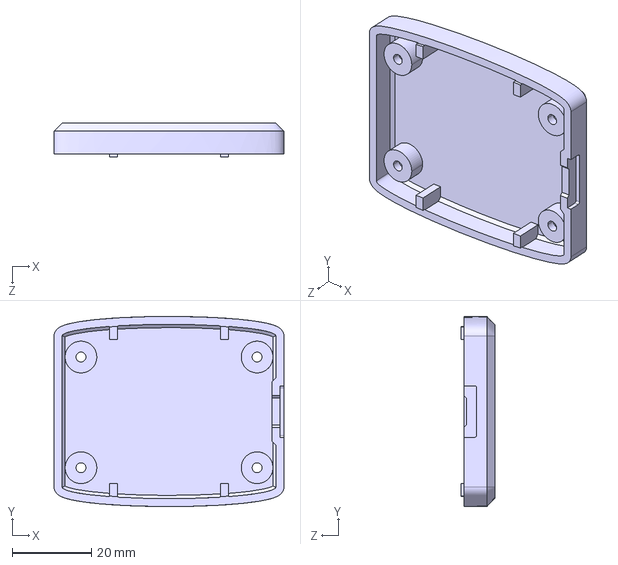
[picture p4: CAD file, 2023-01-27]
Project/V2/Case/Bottom.STEP
58.1 x 48.0 x 8.50 mm

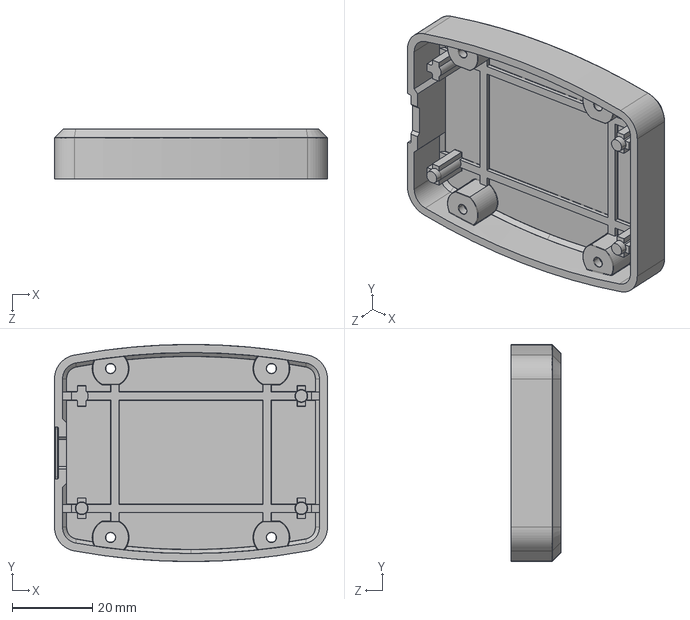
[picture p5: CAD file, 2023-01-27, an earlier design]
Project/V1/Case #1 - Internal Flat Battery/Bottom.STEP
67.9 x 54.0 x 12.5 mm

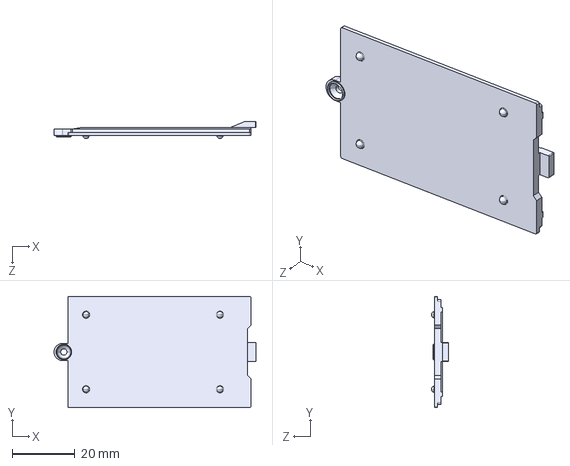
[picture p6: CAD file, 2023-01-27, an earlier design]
Project/V1/Case #2 - External Flat Battery/Battery Cover.STEP
64.5 x 35.5 x 5.50 mm

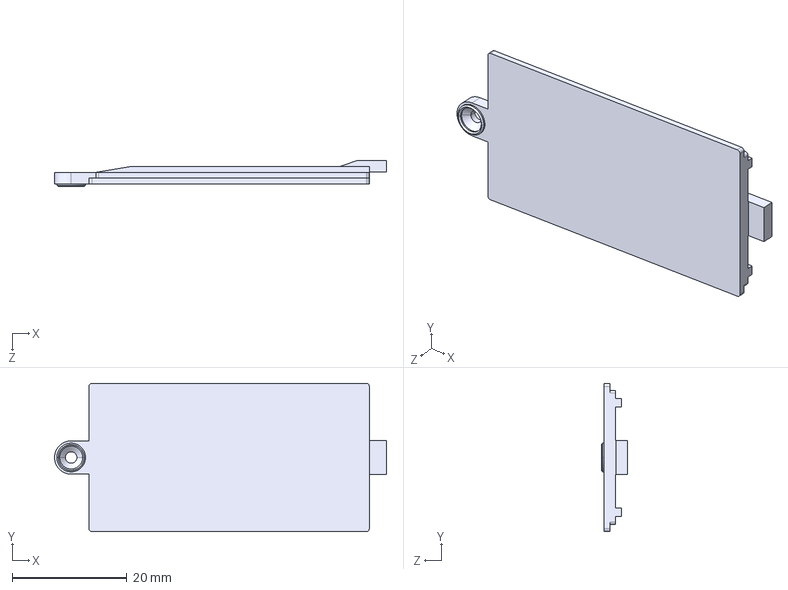
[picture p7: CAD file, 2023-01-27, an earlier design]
Project/V1/Case #3 - External Battery/Battery Cover.STEP
57.8 x 25.8 x 4.60 mm

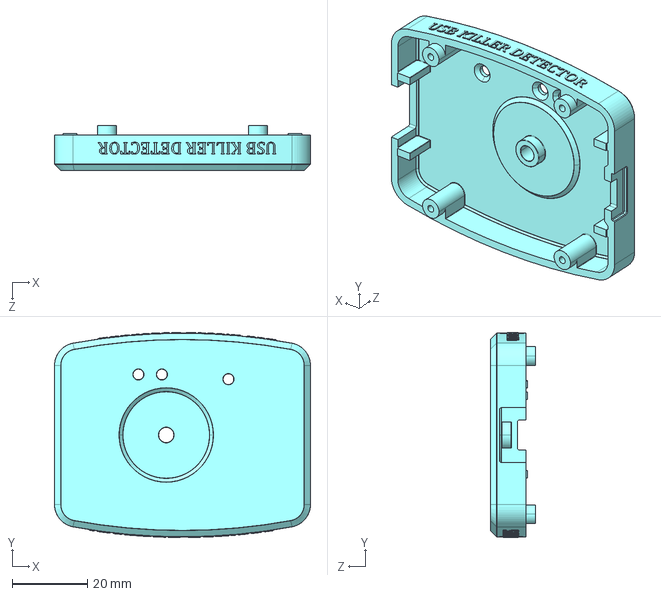
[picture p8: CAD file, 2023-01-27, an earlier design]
Project/V1/Case #1 - Internal Flat Battery/Top.STEP
67.9 x 54.4 x 12.0 mm

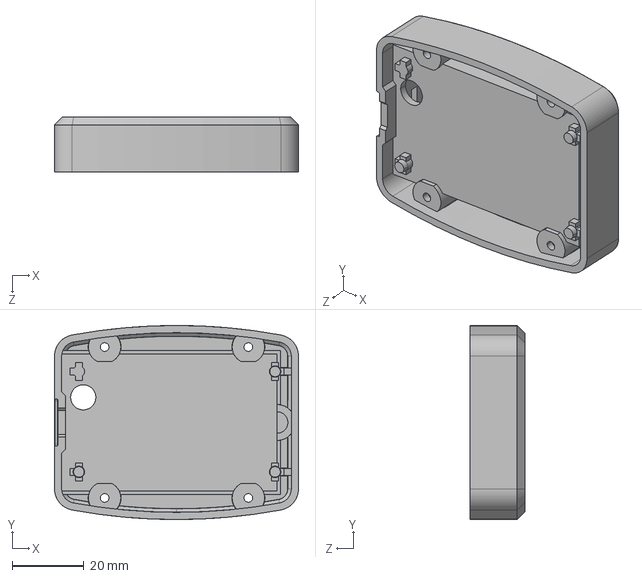
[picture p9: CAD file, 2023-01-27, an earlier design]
Project/V1/Case #2 - External Flat Battery/Bottom.STEP
67.9 x 54.0 x 15.3 mm

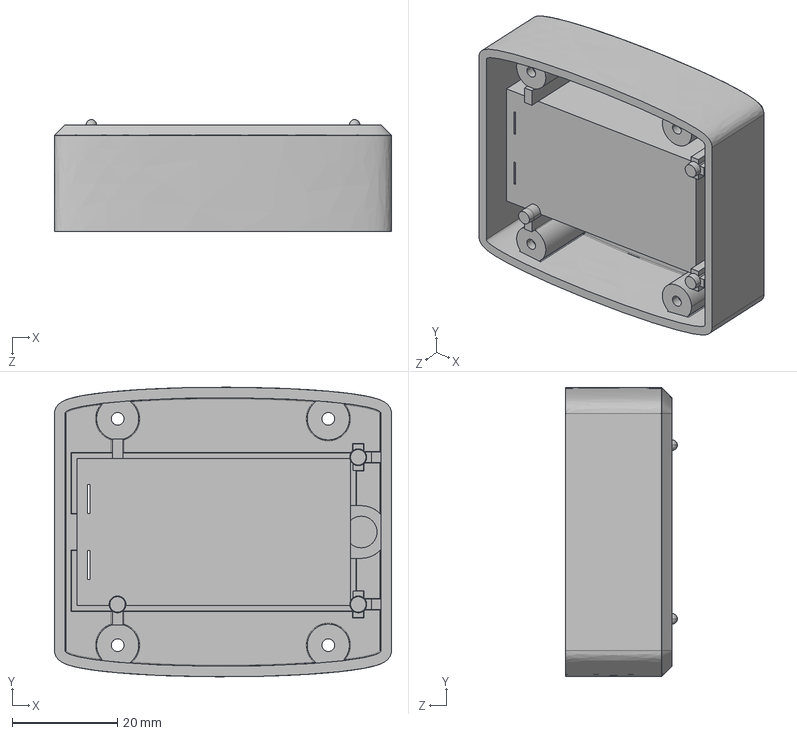
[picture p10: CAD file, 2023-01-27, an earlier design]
Project/V1/Case #3 - External Battery/Bottom.STEP
64.0 x 55.0 x 21.3 mm

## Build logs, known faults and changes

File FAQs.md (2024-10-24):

<p align="center"><strong>FREQUENTLY ASKED QUESTIONS</strong></p>

<hr>
<p><strong>1) How many versions does this project has?</strong></p>
<p><em>Version #1: Battery-powered version.<br>Version #2: Non-battery powered version. It uses a micro-USB cable to obtain power.</em></p>

<hr>
<p><strong>2) Does this device require batteries?</strong></p>
<p><em>Yes, version #1 of this device requires the following battery:</em></p>
<p><em><a href="https://www.digikey.com/en/products/detail/sparkfun-electronics/PRT-13813/6605198" rel="nofollow">https://www.digikey.com/en/products/detail/sparkfun-electronics/PRT-13813/6605198</a><br>
<a href="https://www.sparkfun.com/products/13813" rel="nofollow">https://www.sparkfun.com/products/13813</a></em></p>

<hr>
<p><strong>3) Can I recharge batteries?</strong></p>
<p><em>Of course!</em></p>

<hr>
<p><strong>4) Will a regular USB flash drive be damaged if connected to device?</strong></p>
<p><em>No, regular USB flash drives are not damaged. USB Kill will still be functional after detection.</em></p>

<hr>
<p><strong>5) Can this device be used as a middle point between USB flash drive and computer / phone?</strong></p>
<p><em>No, device will only show if USB flash drive inserted is a USB Kill. Data transference is not possible in any of these versions at this time. It is a future development.</em></p>

<hr>
<p><strong>6) How do I know if device is on, charging or if USB flash drive will damage my computer / phone?</strong></p>
<p><em>Version 1:
- Charging = yellow light turns on.
- On (ready to detect) = green light.
- USB Kill detected = red light turns on.</em></p>
<p><em>Version 2:
- Ready to detect = yellow light turns on.
- USB Kill detected = red light turns on.</em></p>

<hr>
<p><strong>7) How long does a battery charge last?</strong></p>
<p><em>This depends on the use. Regularly, a fully charged battery can last several days.</em></p>

<hr>
<p><strong>8) How should I use this device?</strong></p>
<p><em>Insert USB flash drive into USB port and press switch. Repeat this step at least 2 times. Keep an eye on the red light for results because if red light turns on means that USB flash drive is a USB Kill.</em></p>

<hr>
<p><strong>9) Is there a limit in the number of times I can detect a USB Kill?</strong></p>
<p><em>Battery charge is the limitation on version 1. A charge cable with electricity is the limitation on version 2.</em></p>

<hr>
<p><strong>10) Does this device have a case?</strong></p>
<p><em>There are three different cases available for version #1.
- Case 1: Internal Flat Battery (non-removable). A Nomex Sheet between battery and PCB is recommended.
- Case 2: External Flat Battery (removable). This cable is recommended: <a href="https://www.adafruit.com/product/1131" rel="nofollow">https://www.adafruit.com/product/1131</a>
- Case 3: Two external batteries.</em></p>
<p><em>There is one case for version #2.</em></p>

<hr>
<p><strong>11) What company and configuration do you recommend for 3D printing cases?</strong></p>
<p><em>We recommend using Sculpteo:
- SLS (Plastic)
- Nylon PA12 100-120&mu; (White)
- Finish: Dyed Polished, Black</em></p>

<hr>
<p><strong>12) What charger do you recommend to charge device?</strong></p>
<p><em>Regular micro-USB phone chargers with an output of 5V/1A or also 5V/2A.</em></p>

<hr>
<p><strong>13) What screws do cases use?</strong></p>
<p><em>Self-tapping M2x6 screws.</em></p>

<hr>
<p><strong>14) Is there any troubleshooting guide?</strong></p>
<p><em>Yes, there is a troubleshooting guide for PCB assembly and quick testing.</em></p>
<hr>

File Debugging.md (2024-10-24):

<p align="center">
    <strong>QUICK DEBUGGING</strong>
</p>
<hr>
<p>
    Components D1 and D5 should not be hot. However, they can be hot when it
    suppresses a power surge but, without power surge, they should not get hot.
</p>
<p>
    This device has internal diodes only. Please note that one pin is left un
    connected (VBUS pin).
</p>
<p>
    If users incorrectly solder these components (D1 and D5) and that
    particular unwanted pin is connected to power rail mistakenly, then diodes
    should get hot.
</p>
<p>
    Other reason for the abnormal heat is due to soldering.
</p>
<p>
    If user inserted a USB Killer to device and components D1 and D5 got hot,
    then may be these components are already dead by now.
</p>
<p>
    If this is the case, please remove components and continue lecture.
</p>

<hr>

<p>
    Next step is checking voltage of the main surge detector IC (NX20P0408).
</p>
<p>
    User should check any GND pin of the circuit with D8 diode’s pin (USB side
    pin). This should be nearly 5V.
</p>
<p>
    If it is not nearly 5V, user has to check boost converter output voltage.
    It is TP12 and GND (not in above schematic).
</p>
<p>
    Then user needs some small voltage (limited current) source which can feed
    into USB Bus (bench power supply may work if user adjusts the current
    limiter around 300mA-500mA).
</p>
<p>
    Slowly user needs to increase the voltage up to around 28V at USB Data pins
    and check whether the main detector is triggered or not.
</p>
<p>
    To see if main detector is triggered, please check TP4 and +5V line with
    your voltmeter. If a power surge is detected, then voltmeter should show a
    value of around +5V. If this happens, user can conclude that the main
    detector IC is working.
</p>

<hr>

<p>
    If there are not around +5V in your voltmeter while checking TP4 and +5V
    line, then main surge detector IC (NX20P0408) is not working as it should.
</p>
<p>
    The above can be due to several reasons:
</p>
<p>
    - IC (NX20P0408) was not soldered correctly.
</p>
<p>
    - Components in wrong positions.
</p>
<p>
    - Components soldered incorrectly.
</p>
<p>
    - Not all components are on board.
</p>
<p>
    At this point, it is recommended try to fix any of the above issues or
    start from zero.
</p>

<hr>

<p>
    However, if there were +5V in the voltmeter while checking TP4 and +5V,
    then also check the resistance of F1. It should be very low.
</p>
<p>
    F1 acts as a conductor for normal operation.
</p>
